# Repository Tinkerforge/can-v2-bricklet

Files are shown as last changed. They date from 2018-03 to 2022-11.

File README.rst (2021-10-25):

CAN Bricklet 2.0
================

This repository contains the firmware source code and the hardware design
files. The documentation generator configs can be found at
https://github.com/Tinkerforge/generators

Repository Content
------------------

software/:
 * examples/: Examples for all supported languages
 * build/: Compiled files
 * src/: Source code of firmware
 * Makefile: Makefile to build project

hardware/:
 * Contains KiCad project files and additionally schematics as PDF

datasheets/:
 * Contains datasheets for sensors and complex ICs that are used

Hardware
--------

The hardware is designed with the open source EDA Suite KiCad
(http://www.kicad.org). Before you are able to open the files,
you have to install the Tinkerforge kicad-libraries
(https://github.com/Tinkerforge/kicad-libraries). You can either clone
them directly in hardware/ or clone them in a separate folder and
symlink them into hardware/
(ln -s kicad_path/kicad-libraries project_path/hardware). After that you
can open the .pro file in hardware/ with KiCad and from there view and
modify the schematics and the PCB layout.

Software
--------

If you want to do your own Brick/Bricklet firmware development we highly
recommend that you use our build environment setup script and read the
tutorial (https://www.tinkerforge.com/en/doc/Tutorials/Tutorial_Build_Environment/Tutorial.html).

To compile the C code we recommend you to install the newest GNU Arm Embedded
Toolchain (https://launchpad.net/gcc-arm-embedded/+download).
You also need to install bricklib2 (https://github.com/Tinkerforge/bricklib2).

You can either clone it directly in software/src/ or clone it in a
separate folder and symlink it into software/src/
(ln -s bricklib_path/bricklib2 project_path/software/src/). Finally make sure to
have CMake installed (http://www.cmake.org/cmake/resources/software.html).

After that you can build the firmware by invoking make in software/.
The firmware (.zbin) can then be found in software/build/ and uploaded
with brickv (click button "Flashing" on start screen).

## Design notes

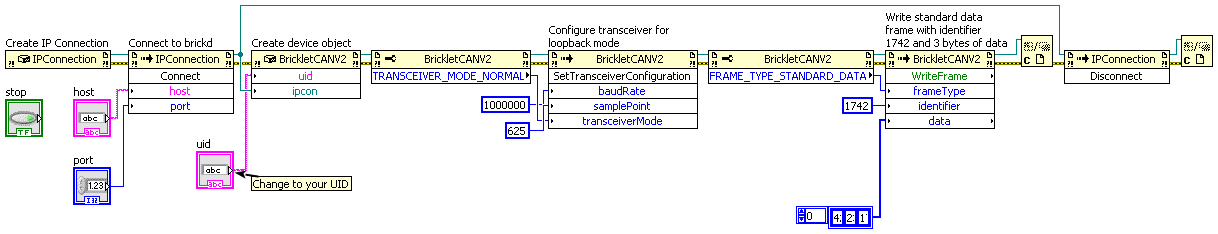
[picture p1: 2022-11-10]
software/examples/labview/Example Write.vi.png

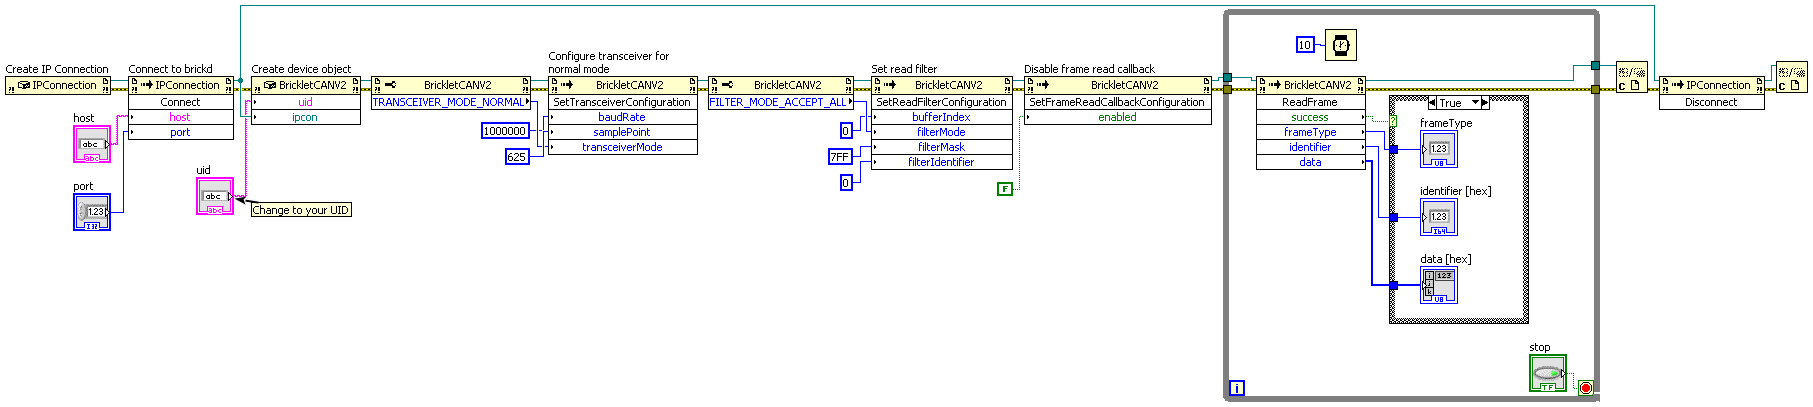
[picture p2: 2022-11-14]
software/examples/labview/Example Read.vi.png

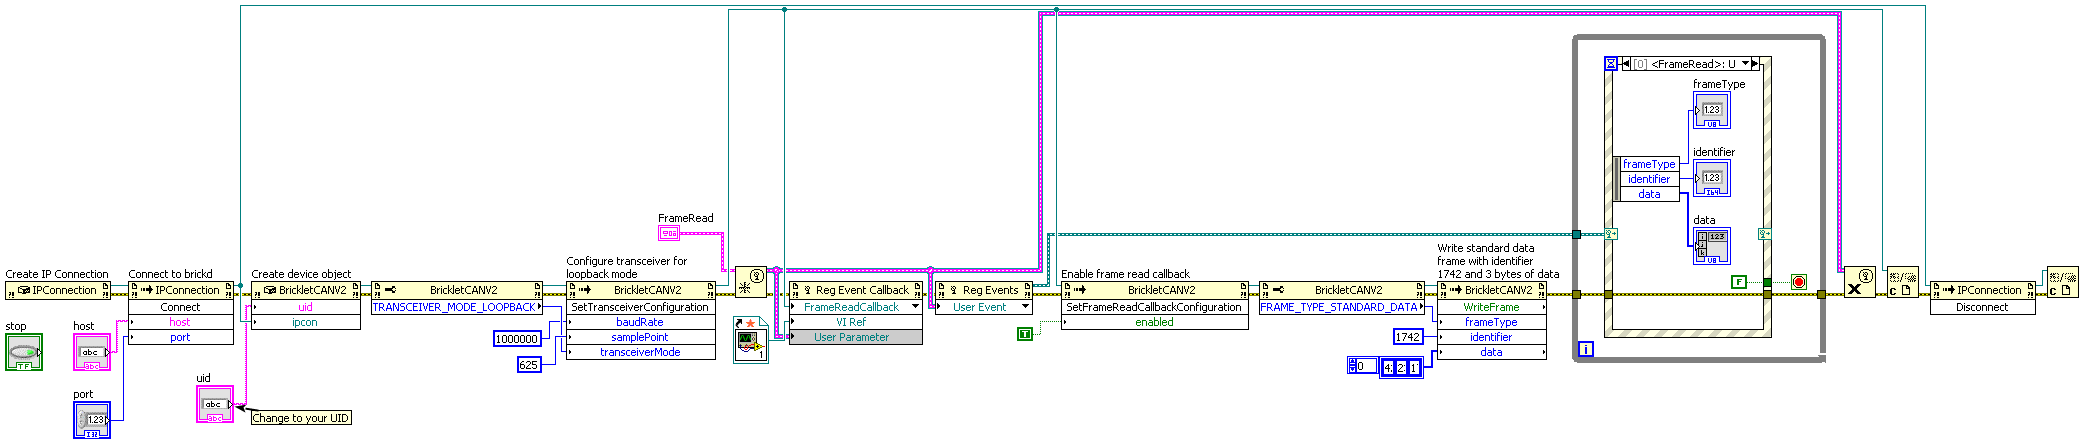
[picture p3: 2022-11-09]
software/examples/labview/Example Loopback.vi.png

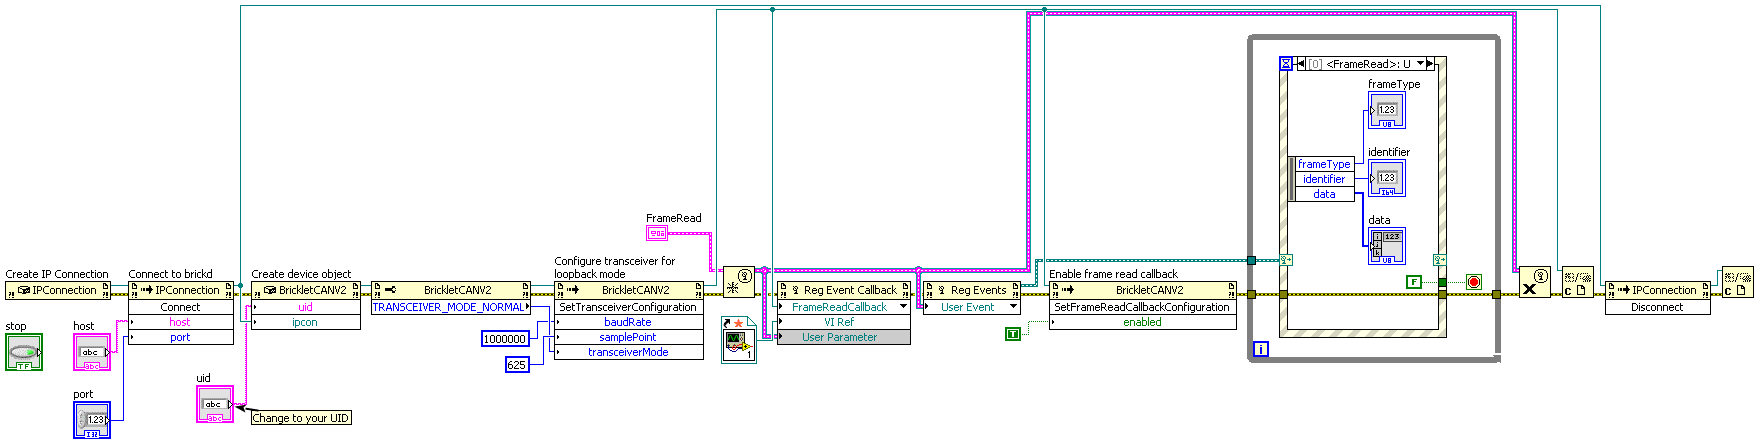
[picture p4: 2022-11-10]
software/examples/labview/Example Read Callback.vi.png

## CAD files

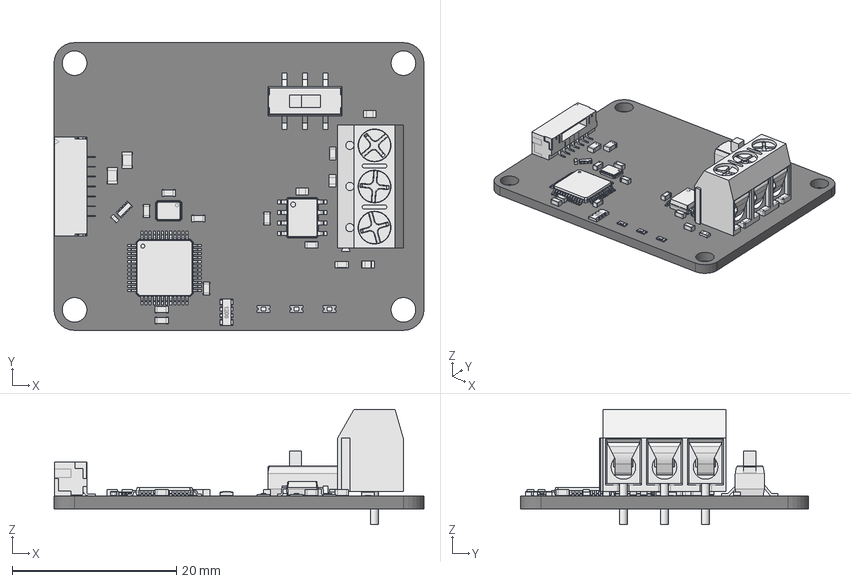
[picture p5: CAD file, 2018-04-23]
hardware/can-v2.FCStd
45.0 x 35.0 x 14.0 mm
Pcb
silde_switch_smd_
3er_Buchse_
C_0402_
C_0805_
C_0805_001
C_0603_
C_0603_001
C_0603_002
C_0603_003
C_0603_004
C_0603_005
C_0603_006
C_0603_007
C_0603_008
C_0603_009
D_0603_blue_
R_0603_
R_0603_001
R_0603_002
R_0603_003
lqfp48_7x7_p05_
soic_8_39x49_p127_
BrickletConn_7pin_
D_0603_red_
R_4x0603_

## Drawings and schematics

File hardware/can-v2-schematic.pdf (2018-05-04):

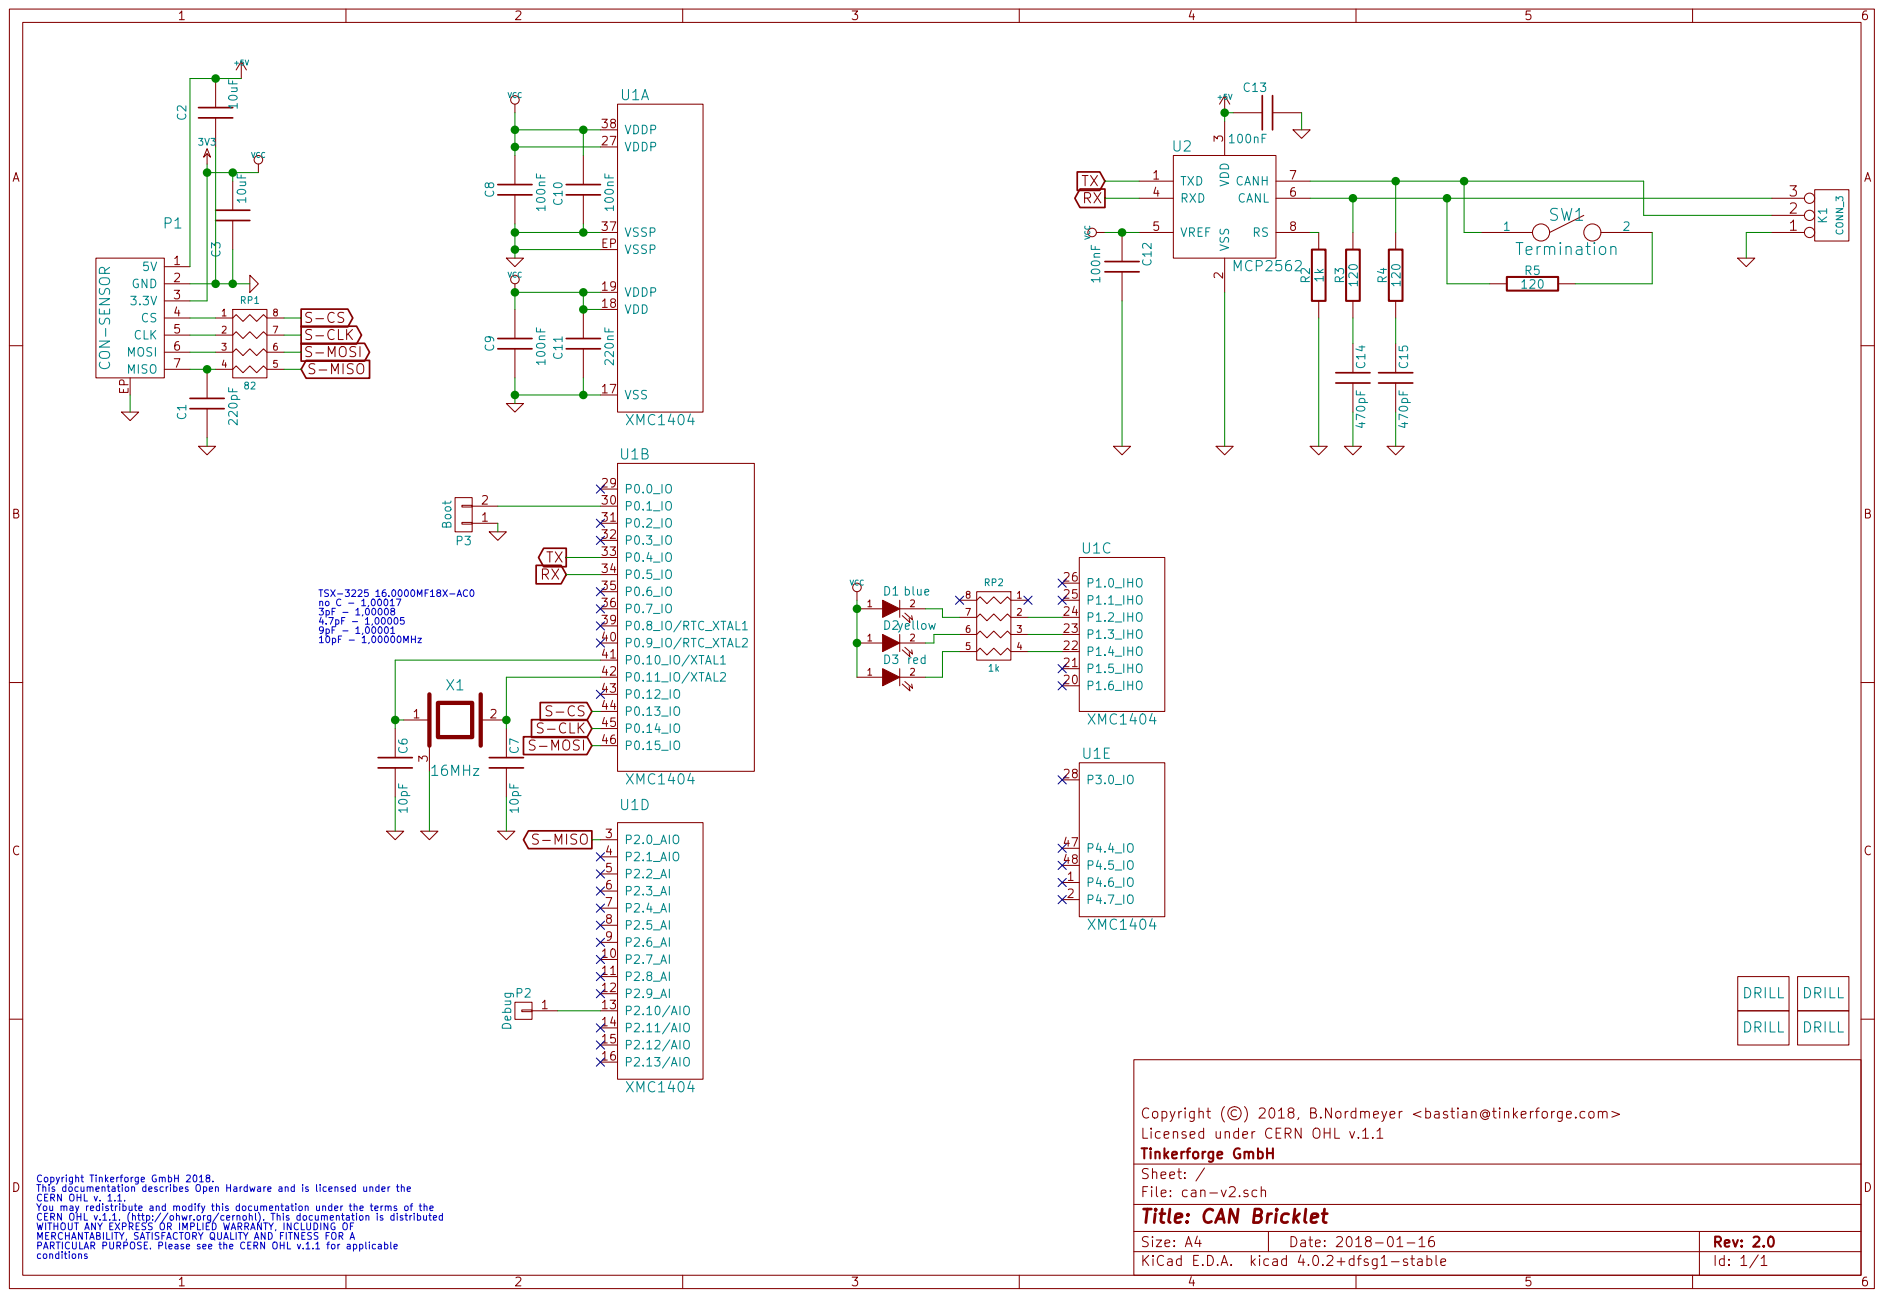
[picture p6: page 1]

Licensed under CERN OHL v.1.1 Copyright (©) 2018, B.Nordmeyer <bastian@tinkerforge.com>

Id: 1/1 Title: CAN Bricklet File: can-v2.sch Sheet: / Tinkerforge GmbH

Copyright Tinkerforge GmbH 2018. This documentation describes Open Hardware and is licensed under the CERN OHL v. 1.1. You may redistribute and modify this documentation under the terms of the CERN OHL v.1.1. (http://ohwr.org/cernohl). This documentation is distributed WITHOUT ANY EXPRESS OR IMPLIED WARRANTY, INCLUDING OF MERCHANTABILITY, SATISFACTORY QUALITY AND FITNESS FOR A

PARTICULAR PURPOSE. Please see the CERN OHL v.1.1 for applicable

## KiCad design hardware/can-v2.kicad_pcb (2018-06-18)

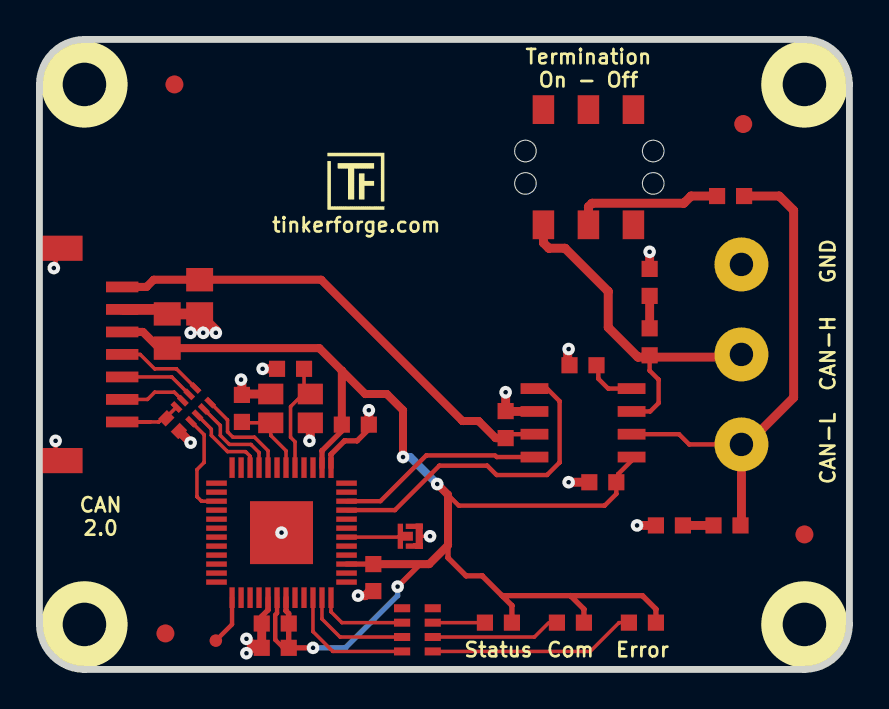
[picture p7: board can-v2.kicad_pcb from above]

Board: 2 copper layers, 45.0 x 35.0 mm, 40 parts (0 on the bottom side), 29 nets.

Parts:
C1: 220pF; C0402F
C2, C3: 10uF; C0805E
C6, C7: 10pF; C0603F
C8, C9, C10, C12, C13: 100nF; C0603F
C11: 220nF; C0603F
C14, C15: 470pF; C0603F
D1: blue; D0603F
D2: yellow; D0603F
D3: red; D0603F
Fiducial_Mark: VAL**; Fiducial_Mark
Fiducial_Mark#2, Fiducial_Mark#3, Fiducial_Mark#4: VAL**; Fiducial_Mark
K1: CONN_3; AKL_5_3
P1: CON-SENSOR; CON-SENSOR2
P2: Debug; DEBUG_PAD
P3: Boot; SolderJumper
R2: 1k; R0603F
R3, R4, R5: 120; R0603F
RP1: 82; 4X0402
RP2: 1k; 0603X4
SW1: Termination; SLIDE_SWITCH
U1: XMC1404; QFN48-EP2
U2: MCP2562; SOIC8
U3, U4, U5, U6: DRILL; DRILL_NP
VAL: WEEE_7mm
VAL#2: CE_5mm
X1: 16MHz; CRYSTAL_3225

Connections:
3V3: C3.2, C8.2, C9.2, C10.2, C11.2, C12.1, D1.1, D2.1, D3.1, P1.3, U1.18, U1.19, U1.27, U1.38, U2.5
+5V: C2.2, C13.1, P1.1, U2.3
GND: C1.1, C2.1, C3.1, C6.2, C7.2, C8.1, C9.1, C10.1, C11.1, C12.2, C13.2, C14.2, C15.2, K1.1, P1.2, P1.EP, P3.1, R2.1, U1.17, U1.37, U1.EP, U2.2, X1.3
unnamed: C1.2, P1.7, RP1.4
unnamed: C6.1, U1.41, X1.1
unnamed: C7.1, U1.42, X1.2
unnamed: C14.1, R3.1
unnamed: C15.1, R4.1
unnamed: D1.2, RP2.7
unnamed: D2.2, RP2.6
unnamed: D3.2, RP2.5
unnamed: K1.2, R4.2, SW1.1, U2.7
unnamed: K1.3, R3.2, R5.1, U2.6
unnamed: P1.4, RP1.1
unnamed: P1.5, RP1.2
unnamed: P1.6, RP1.3
unnamed: P2.1, U1.13
unnamed: P3.2, U1.30
unnamed: R2.2, U2.8
unnamed: R5.2, SW1.2
unnamed: RP2.2, U1.24
unnamed: RP2.3, U1.23
unnamed: RP2.4, U1.22
RX: U1.34, U2.4
S-CLK: RP1.7, U1.45
S-CS: RP1.8, U1.44
S-MISO: RP1.5, U1.3
S-MOSI: RP1.6, U1.46
TX: U1.33, U2.1

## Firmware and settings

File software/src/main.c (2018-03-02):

/* can-v2-bricklet
 * Copyright (C) 2018 Matthias Bolte <matthias@tinkerforge.com>
 *
 * main.c: Initialization for CAN V2 Bricklet
 *
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
 * You should have received a copy of the GNU Lesser General Public
 * License along with this library; if not, write to the
 * Free Software Foundation, Inc., 59 Temple Place - Suite 330,
 * Boston, MA 02111-1307, USA.
 */

#include <stdio.h>
#include <stdbool.h>

#include "configs/config.h"

#include "bricklib2/bootloader/bootloader.h"
#include "bricklib2/hal/system_timer/system_timer.h"
#include "bricklib2/logging/logging.h"
#include "communication.h"
#include "tfcan.h"

// xmc_can.c uses OSCHP_GetFrequency so implement it here
__WEAK uint32_t OSCHP_GetFrequency(void)
{
	return OSCHP_FREQUENCY;
}

int main(void) {
	logging_init();
	logd("Start CAN V2 Bricklet\n\r");

	communication_init();
	tfcan_init();

	while(true) {
		bootloader_tick();
		communication_tick();
		tfcan_tick();
	}
}

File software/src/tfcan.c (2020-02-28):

/* can-v2-bricklet
 * Copyright (C) 2018-2019 Matthias Bolte <matthias@tinkerforge.com>
 *
 * tfcan.c: Transfer data over CAN bus
 *
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
 * You should have received a copy of the GNU Lesser General Public
 * License along with this library; if not, write to the
 * Free Software Foundation, Inc., 59 Temple Place - Suite 330,
 * Boston, MA 02111-1307, USA.
 */

#include "tfcan.h"

#include "configs/config.h"
#include "configs/config_tfcan.h"
#include "bricklib2/hal/system_timer/system_timer.h"
#include "bricklib2/logging/logging.h"

#include "xmc_gpio.h"
#include "xmc_can.h"
#include "xmc_can_map.h"

TFCAN tfcan;

void IRQ_Hdlr_0(void) {
	for (uint8_t i = 0; i < TFCAN_NODE_SIZE; ++i) {
		const uint32_t nsr = tfcan.node[i]->NSR;
		const uint8_t lec = (nsr & (uint32_t)CAN_NODE_NSR_LEC_Msk) >> CAN_NODE_NSR_LEC_Pos;

		if ((nsr & (uint32_t)CAN_NODE_NSR_BOFF_Msk) != 0 && lec == TFCAN_NODE_LEC_BIT0_ERROR) {
			// in bus-off mode the transceiver uses the bit0 flag to indicate that
			// 11 recessive bits have been received. therefore, this is not an error
			continue;
		}

		switch (lec) {
			case TFCAN_NODE_LEC_STUFFING_ERROR: tfcan.error_occurred = true; ++tfcan.transceiver_stuffing_error_count; break;
			case TFCAN_NODE_LEC_FORMAT_ERROR:   tfcan.error_occurred = true; ++tfcan.transceiver_format_error_count;   break;
			case TFCAN_NODE_LEC_ACK_ERROR:      tfcan.error_occurred = true; ++tfcan.transceiver_ack_error_count;      break;
			case TFCAN_NODE_LEC_BIT1_ERROR:     tfcan.error_occurred = true; ++tfcan.transceiver_bit1_error_count;     break;
			case TFCAN_NODE_LEC_BIT0_ERROR:     tfcan.error_occurred = true; ++tfcan.transceiver_bit0_error_count;     break;
			case TFCAN_NODE_LEC_CRC_ERROR:      tfcan.error_occurred = true; ++tfcan.transceiver_crc_error_count;      break;
			default:                                                                                                   break;
		}
	}
}

void tfcan_init(void) {
	logd("sizeof(TFCAN) %u\n\r", sizeof(TFCAN));

	memset(&tfcan, 0, sizeof(TFCAN));

	tfcan.reconfigure_transceiver = true;
	tfcan.reconfigure_queues = true;
	tfcan.reconfigure_rx_filters = 0;

	tfcan.baud_rate = 125000; // config default
	tfcan.sample_point = 625; // config default
	tfcan.sync_jump_width = 1;
	tfcan.transceiver_mode = TFCAN_TRANSCEIVER_MODE_NORMAL; // config default
	tfcan.timestamped_frame_enabled = false;

	tfcan.node[0] = CAN_NODE0;
	tfcan.node[1] = CAN_NODE1;
	tfcan.tx_node = tfcan.node[0];
	tfcan.rx_node = tfcan.node[0];

	tfcan.tx_buffer_size = TFCAN_BUFFER_SIZE / 4; // config default
	tfcan.tx_buffer_timeout = 0; // config default

	tfcan.rx_buffer_size[0] = TFCAN_BUFFER_SIZE / 2; // config default
	tfcan.rx_buffer_type[0] = TFCAN_BUFFER_TYPE_DATA; // config default

	tfcan.rx_buffer_size[1] = TFCAN_BUFFER_SIZE / 4; // config default
	tfcan.rx_buffer_type[1] = TFCAN_BUFFER_TYPE_REMOTE; // config default

	for (uint8_t i = 0; i < TFCAN_BUFFER_SIZE; ++i) {
		tfcan.rx_filter_mode[i] = TFCAN_FILTER_MODE_ACCEPT_ALL; // config default
		tfcan.rx_filter_mask[i] = 0; // config default
		tfcan.rx_filter_identifier[i] = 0; // config default
	}

	tfcan.tx_backlog_size = TFCAN_BACKLOG_SIZE / 2; // config default
	tfcan.tx_timestamped_backlog_size = TFCAN_TIMESTAMPED_BACKLOG_SIZE / 2; // config default

	tfcan.rx_backlog_size = TFCAN_BACKLOG_SIZE / 2; // config default
	tfcan.rx_timestamped_backlog_size = TFCAN_TIMESTAMPED_BACKLOG_SIZE / 2; // config default

#ifdef TFCAN_BUFFER_DEBUG
	tfcan.last_buffer_debug = system_timer_get_ms();
#endif

	// configure clock
	XMC_CAN_Init(CAN, TFCAN_CLOCK_SOURCE, TFCAN_FREQUENCY);

	// enter config mode
	tfcan_set_config_mode(true);

	// configure RX pin
	const XMC_GPIO_CONFIG_t rx_pin_config = {
		.mode             = XMC_GPIO_MODE_INPUT_TRISTATE,
		.input_hysteresis = XMC_GPIO_INPUT_HYSTERESIS_STANDARD,
	};

	XMC_GPIO_Init(TFCAN_RX_PIN, &rx_pin_config);
	XMC_CAN_NODE_SetReceiveInput(tfcan.node[0], TFCAN_RECEIVE_INPUT);

	// configure TX pin
	const XMC_GPIO_CONFIG_t tx_pin_config = {
		.mode         = XMC_GPIO_MODE_OUTPUT_PUSH_PULL_ALT9,
		.output_level = XMC_GPIO_OUTPUT_LEVEL_HIGH
	};

	XMC_GPIO_Init(TFCAN_TX_PIN, &tx_pin_config);

	// leave config mode
	tfcan_set_config_mode(false);

	// configure transceiver and queues
	tfcan_reconfigure_transceiver();
	tfcan_reconfigure_queues();

	tfcan.transceiver_state = TFCAN_TRANSCEIVER_STATE_ACTIVE;
	tfcan.transceiver_tx_error_level = 0;
	tfcan.transceiver_rx_error_level = 0;
	tfcan.transceiver_stuffing_error_count = 0;
	tfcan.transceiver_format_error_count = 0;
	tfcan.transceiver_ack_error_count = 0;
	tfcan.transceiver_bit1_error_count = 0;
	tfcan.transceiver_bit0_error_count = 0;
	tfcan.transceiver_crc_error_count = 0;
	tfcan.tx_buffer_timeout_error_count = 0;
	tfcan.rx_buffer_overflow_error_count = 0;
	tfcan.rx_buffer_overflow_error_occurred = 0;
	tfcan.rx_backlog_overflow_error_count = 0;

	// configure LEC interrupt
	NVIC_EnableIRQ(TFCAN_NODE_LEC_IRQ_INDEX);
	NVIC_SetPriority(TFCAN_NODE_LEC_IRQ_INDEX, 0);
	XMC_SCU_SetInterruptControl(TFCAN_NODE_LEC_IRQ_INDEX, XMC_SCU_IRQCTRL_CAN0_SR0_IRQ0);

	// configure communication LED
	XMC_GPIO_CONFIG_t com_led_pin_config = {
		.mode         = XMC_GPIO_MODE_OUTPUT_PUSH_PULL,
		.output_level = XMC_GPIO_OUTPUT_LEVEL_LOW
	};

	XMC_GPIO_Init(TFCAN_COM_LED_PIN, &com_led_pin_config);

	tfcan.com_led_state.config = LED_FLICKER_CONFIG_STATUS;
	tfcan.com_led_state.counter = 0;
	tfcan.com_led_state.start = 0;

	// configure error LED
	XMC_GPIO_CONFIG_t error_led_pin_config = {
		.mode         = XMC_GPIO_MODE_OUTPUT_PUSH_PULL,
		.output_level = XMC_GPIO_OUTPUT_LEVEL_HIGH
	};

	XMC_GPIO_Init(TFCAN_ERROR_LED_PIN, &error_led_pin_config);

	tfcan.error_led_state.config = LED_FLICKER_CONFIG_EXTERNAL;
	tfcan.error_led_state.counter = 0;
	tfcan.error_led_state.start = 0;

	tfcan.error_led_config = TFCAN_ERROR_LED_CONFIG_SHOW_TRANSCEIVER_STATE;
	tfcan.error_occurred = false;
	tfcan.error_state = TFCAN_ERROR_STATE_IDLE;
}
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

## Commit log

2018-01-16 add prototype hardware
    [can.kicad_pcb, can.sch]
2018-01-19 change text orientation
    [can.kicad_pcb]
2018-02-20 Cleanup KiCad libraries config
    Ensure LibDir=kicad-libraries and LibName1=tinkerforge.
    Remove special library.
2018-03-02 Add initial firmware
    That every seconds sends a dummy data frame.
    [cmake_config_custom.txt]
2018-03-07 Add custom MO helpers to avoid quirks and memory overhead in the XMC library
    [communication.c, tfcan.c]
2018-03-08 Add basic config for extra LEDs
2018-03-08 Extend write-frame to handle remote frames
2018-03-08 Split RX FIFO into multiple RX FIFOs
    To allow reception of data and remote frames along with the ability
    to have multiple acceptance filters, one per RX FIFO.
2018-03-08 Convert write/read-frame functions to streaming
2018-03-08 Add custom baudrate to bit-timing calculation
    The XMC library function for this doesn't take the DIV8 option into
    account and therefore cannot handle baudrates below 100 kbps.
    [tfcan.c]
2018-03-12 Add extra MO type to use last backlog slots
2018-03-12 Use frame-counter to read RF FIFOs in frame reception order
2018-03-13 Add frame-read callback
2018-03-14 Add queue and read filter configuration
2018-03-14 Add communication and error LED config
    [communication.c, communication.h, tfcan.c]
2018-03-15 fix led text
    [can.kicad_pcb]
2018-03-15 fix text, change logo orientation
    [can.kicad_pcb]
2018-03-15 Rename some error related things
    [communication.c, communication.h, tfcan.c]
2018-03-15 Reconfigure queues when entering/leaving loopback mode
    Otherwise the RX queue ends up being on the wrong CAN node, because in
    loopback the second CAN node is used for reception, but in non-loopback
    mode the first CAN node is used for transmission and reception.
    [tfcan.c]
2018-03-15 Don't set RXEN on RX FIFO slave objects
    This is not necessary for proper RX FIFO operation and it results in
    possible reception of frames in the middle of the RX FIFO because
    RX FIFO slave objects are normal message objects that take part in
    the acceptance filtering process if RXEN is set.
    This is especially noticable when using a read filter, because then
    frames that would be rejected by the read filter are recevied into
    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
2018-03-27 specify processor
    [can.kicad_pcb, can.sch]
2018-04-23 Add 3d information (final)
    [can.kicad_pcb]
2018-04-23 Add 3d model (*.FCStd & *.step)
    [can.FCStd]
2018-05-04 Rename files
    [can-v2.FCStd, can-v2.kicad_pcb, can-v2.sch]
2018-05-04 Add schematic PDF
2018-05-30 Add sample-point config option
2018-06-05 Correctly set DIV8 config bit
    [tfcan.c]
2018-06-05 examples: Fix write-frame call
    [example_loopback.c]
2018-06-08 fix termination text
    [can-v2.kicad_pcb]
2018-06-18 Change capacitor footprint(s) to C0402F
    [can-v2.kicad_pcb, can-v2.sch]
2019-08-22 c: Adapt to bindings changes
    [example_loopback.c]
2019-10-04 Add initial support for timestamped frame handling
2020-02-26 Disable incomplete timestamped frame functions for now.
2020-02-27 Add frame readable callback.
2020-02-27 Fix disabled callback list.
    [communication.h]
2020-02-27 Mark error counters used in interrupt volatile.
2020-02-27 Add error occured callback.
    [communication.c, communication.h, tfcan.c]
2020-02-28 Fix bit0 error handling in bus-off mode
    [config.h, tfcan.c]
2020-03-17 examples: Add constant translation for frame type
2020-08-31 uc: Use fixed-with placeholders in format strings.
    [example_loopback.c]
2020-09-02 uc: Add example driver note.
2021-10-25 Update KiCad link
    https://www.kicad.org/blog/2021/10/Avoid-links-to-former-kicad-domain/
2022-04-26 uc: Adapt to bindings changes
    [example_loopback.c]
2022-11-14 labview: Add example for frame-read function
